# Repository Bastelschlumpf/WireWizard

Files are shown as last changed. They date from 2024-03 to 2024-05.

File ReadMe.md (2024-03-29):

# WireWizard "Under Construction"

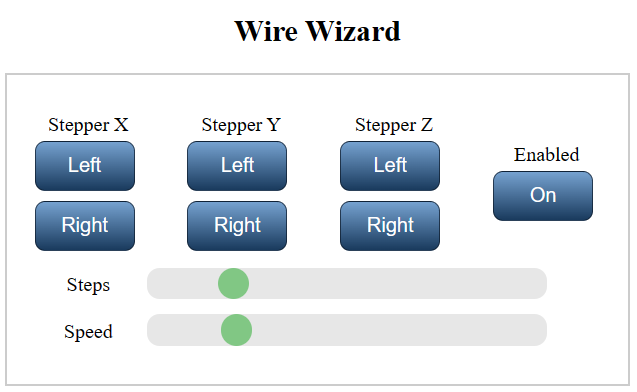
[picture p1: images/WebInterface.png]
WebInterface
 

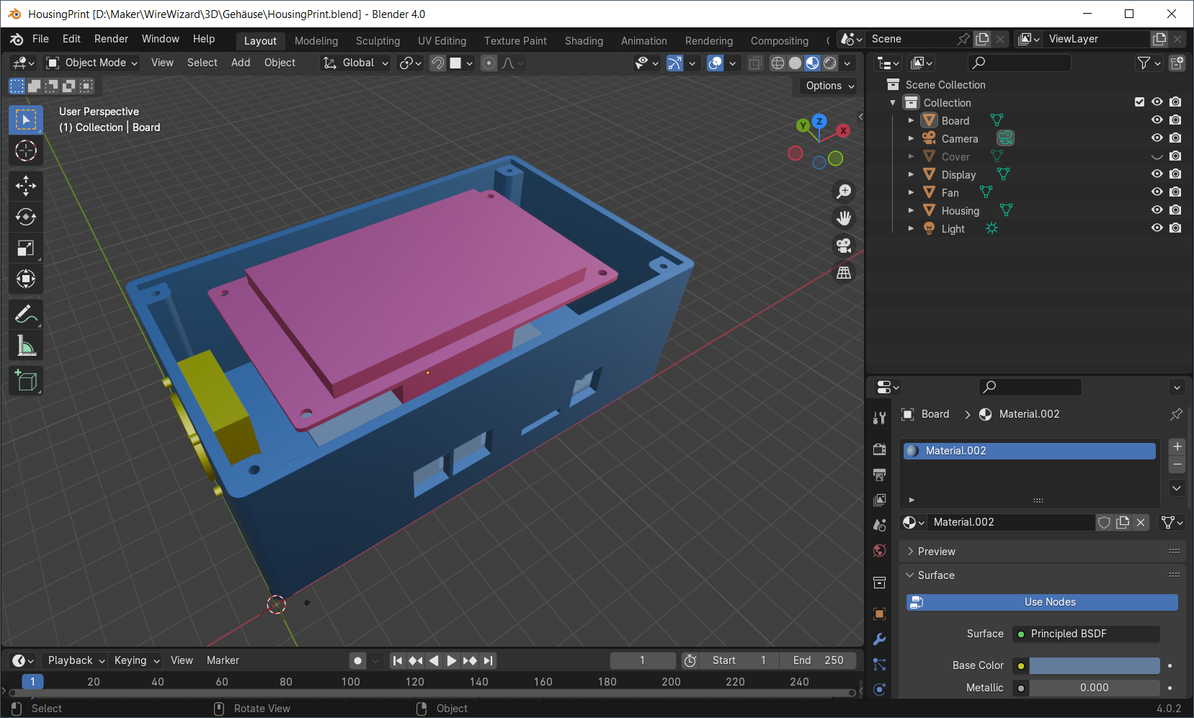
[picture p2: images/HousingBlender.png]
 
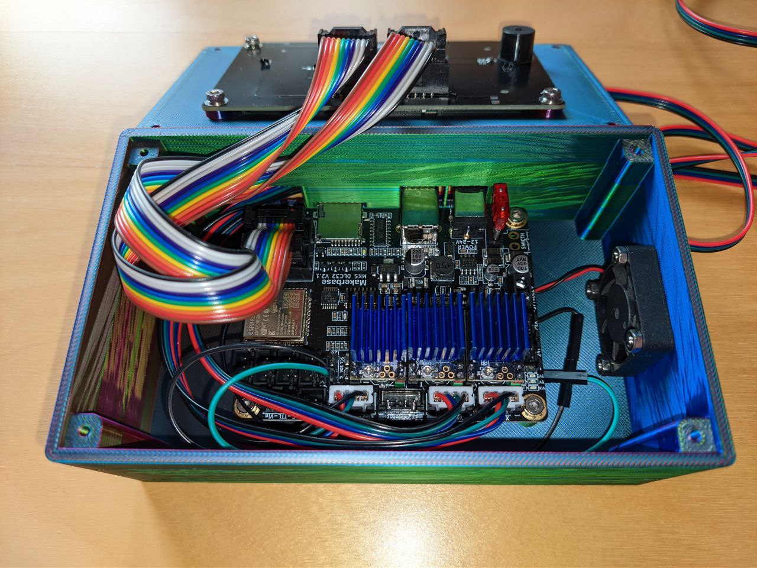
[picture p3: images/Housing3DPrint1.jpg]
 
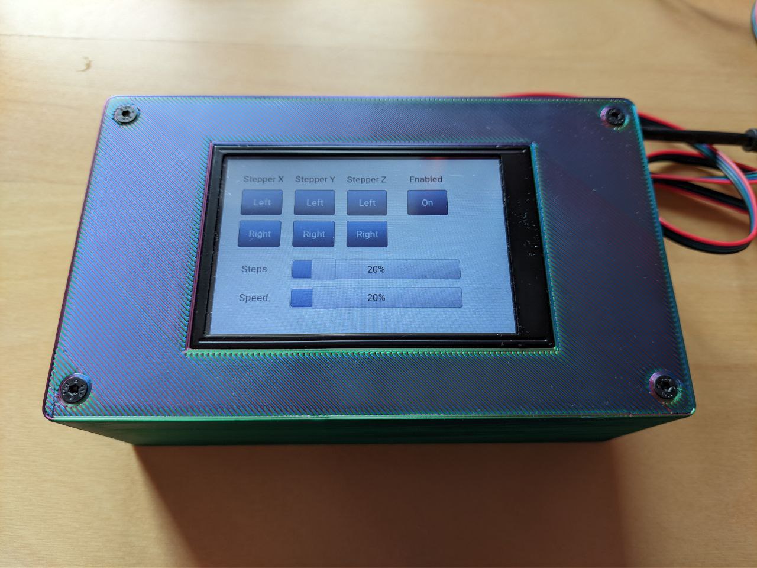
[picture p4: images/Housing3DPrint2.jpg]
 

lvgl Library
  Version 9.0.0
  https://lvgl.io
  
TFT_eSPI Library  
  Version 2.5.43
  https://github.com/Bodmer/TFT_eSPI
  
  **Anpassungen in User_Setup.h**  
  #define ST7796_DRIVER  
  #define TFT_WIDTH  480  
  #define TFT_HEIGHT 320  
  #define TFT_MISO 19  
  #define TFT_MOSI 23  
  #define TFT_SCLK 18  
  #define TFT_CS   25  // Chip select control pin   
  #define TFT_DC   33  // Data Command control pin  
  #define TFT_RST  27  // Reset pin (could connect to RST pin)  
  #define TOUCH_CS 26     // Chip select pin (T_CS) of touch screen  
  // #define SMOOTH_FONT  
  #define SPI_FREQUENCY  40000000  
  #define SPI_TOUCH_FREQUENCY  2000000  

### Special thanks to

**betaone for the universal housing with cover on thingiverse  
https://www.thingiverse.com/thing:1701426**

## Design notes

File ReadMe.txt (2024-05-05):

Gummifüsse
Display schräg
Ein-/Ausschalter

Stepper Klein
  28HS2806A4
Treiber  
  TMC2209
  
Die eingestellte Spannung am TMC22209 Poti muss 0.85 sein für 0.6A
damit es mit dem 28HS2806 Stepper passt. 
https://learn.watterott.com/de/silentstepstick/faq/  

https://github.com/janelia-arduino/TMC2209/blob/main/datasheet/TMC2209_SilentStepStick_datasheet_Rev1.20.pdf

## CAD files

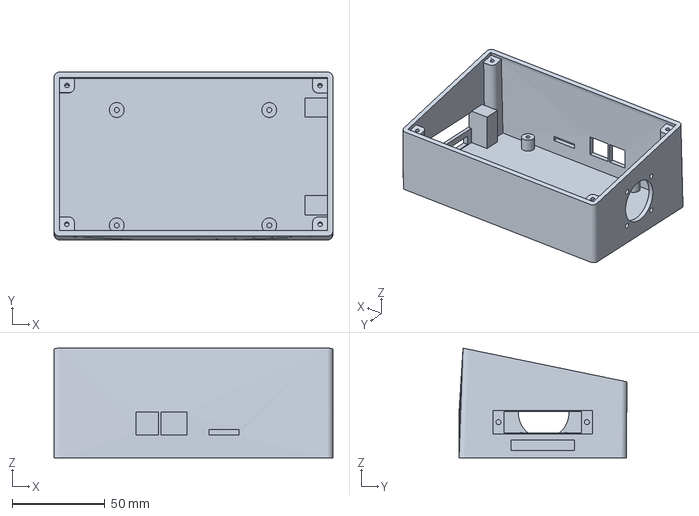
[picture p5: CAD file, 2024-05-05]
housing/ControlBox.3mf
150.0 x 90.3 x 59.0 mm

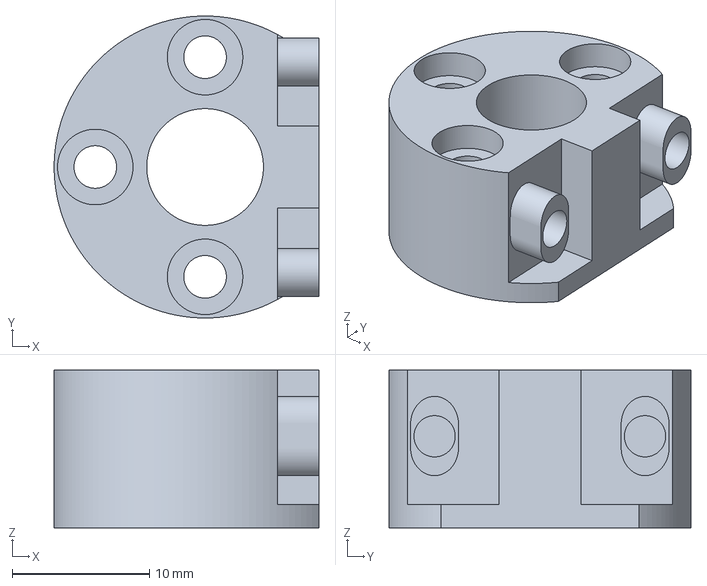
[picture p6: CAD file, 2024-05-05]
housing/parts/KnifeHolder.3mf
19.3 x 22.0 x 11.5 mm

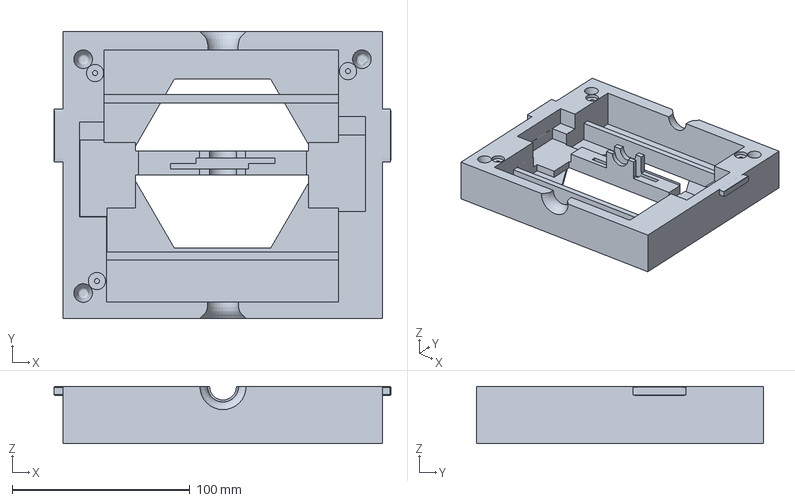
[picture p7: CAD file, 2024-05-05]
housing/CutterBoxCover.3mf
189.9 x 161.7 x 32.1 mm

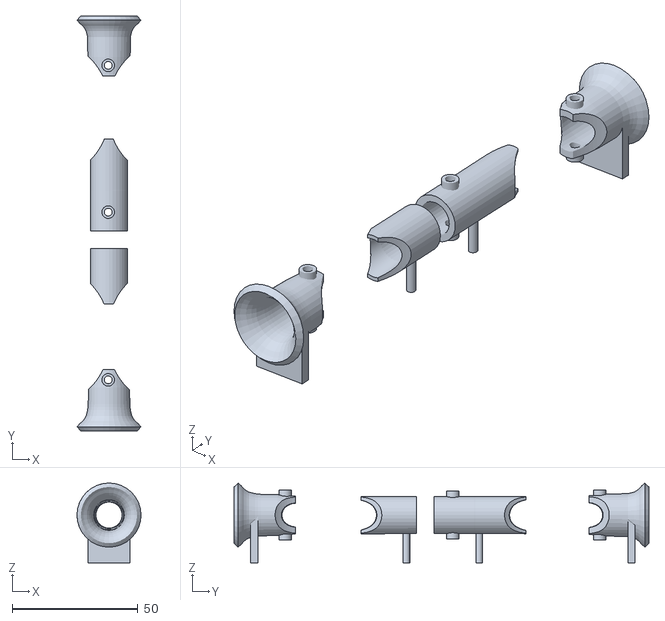
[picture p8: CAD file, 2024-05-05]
housing/parts/Tube.stl
25.5 x 165.0 x 31.8

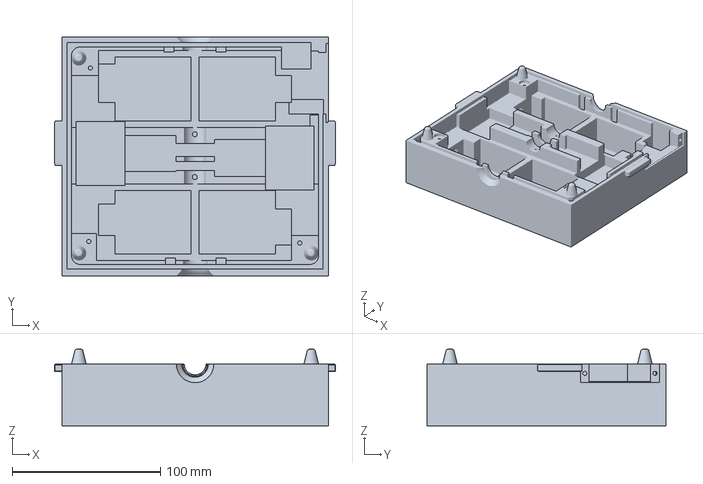
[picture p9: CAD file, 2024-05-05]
housing/CutterBox.3mf
189.9 x 161.7 x 51.8 mm

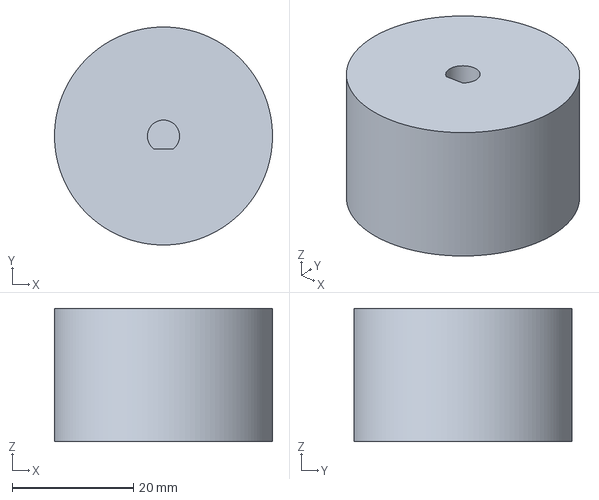
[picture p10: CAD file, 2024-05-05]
housing/parts/DriveRoller.3mf
36.0 x 36.0 x 22.0 mm

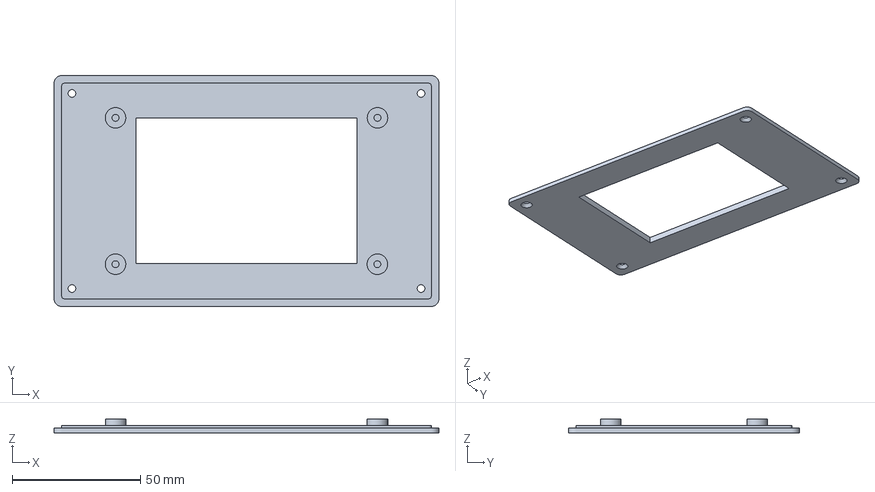
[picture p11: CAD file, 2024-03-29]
housing/ControlBoxCover.3mf
150.0 x 90.0 x 5.52 mm

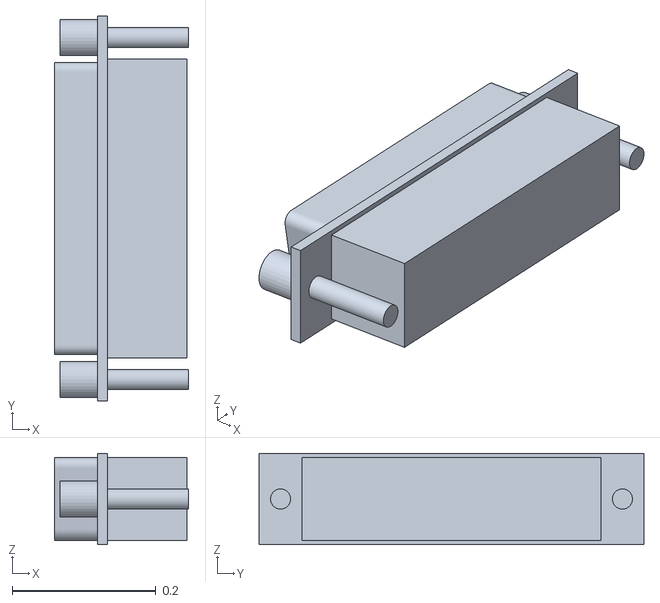
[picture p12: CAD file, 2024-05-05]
housing/parts/D-Sub25.stl
0.187 x 0.535 x 0.127

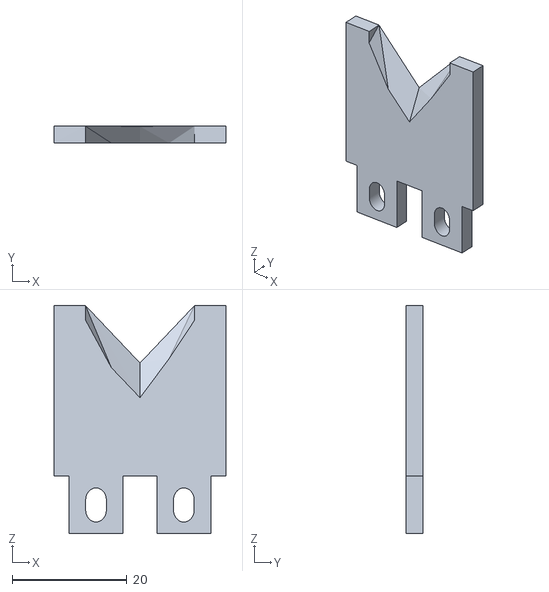
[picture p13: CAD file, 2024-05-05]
housing/parts/Knife.stl
30.0 x 3.00 x 39.8

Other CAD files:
housing/ControlBox.blend
housing/ControlBox.stl
housing/ControlBoxCover.stl
housing/CutterBox.stl
housing/CutterBoxCover.stl
housing/parts/ControlBoard.blend
housing/parts/D-Sub25.blend
housing/parts/Display.blend
housing/parts/DriveRoller.stl
housing/parts/Knife.blend
housing/parts/KnifeHolder.blend
housing/parts/KnifeHolder.stl
housing/parts/LED.blend
housing/parts/Stepper_17HD3401B.blend
housing/parts/Stepper_17HS4023.blend
housing/parts/Tube.blend

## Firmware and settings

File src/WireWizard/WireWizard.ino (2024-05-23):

/*
   Copyright (C) 2024 SFini

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
   You should have received a copy of the GNU General Public License
   along with this program.  If not, see <http://www.gnu.org/licenses/>.
*/
/**
  * @file WireWizard.ino
  * 
  * Main WireWizard file
  */

#include "Config.h"
#define USE_CONFIG_OVERRIDE //!< Switch to use ConfigOverride
#ifdef USE_CONFIG_OVERRIDE
  #include "ConfigOverride.h"
#endif

#include <Arduino.h>
#include <SPI.h>
#include "EventQueue.h"
#include "Sensors.h"
#include "Motors.h"
#include "Controller.h"
#include "Display.h"
#include "WebServer.h"

Motors      motors;
Sensors     sensors;
Controller  controller(motors, sensors);
Display     display;
MyWebServer webServer;


void setup() 
{
  Serial.begin(115200);

  disableCore0WDT();
  disableCore1WDT();

  SPI.begin();

  motors.begin();
  motors.delay(0);
  motors.enable(true);
  motors.enableOnIdle(false);
  sensors.begin();
  controller.begin();
  display.begin();

  // webServer.begin();
}

#define MAX_DELAY 1000
#define MAX_STEPS 10 * 16 * 200

void testCut()
{
  int ticks = millis();

  motors.beep(100);
  motors.delay(1000);

  Serial.println("Fill in");
  ticks = millis();
  motors.stepX(-100000);
  Serial.println("Wait for cutter sensor");
  while (sensors.getY() < 3000) {
    delay(100);
    if (millis() - ticks > 5000) {
      break;
      // return;
    }
  };
  motors.resetSteps();

  Serial.println("Move forward");
  ticks = millis();
  motors.stepX(-100000);
  motors.stepZ(-100000);
  Serial.println("Wait for out sensor");
  while (sensors.getZ() < 3000) {
    delay(100);
    if (millis() - ticks > 5000) {
      break;
      // return;
    }
  };
  motors.resetSteps();

  Serial.println("Move a bit forward");
  ticks = millis();
  motors.stepX(-3000);
  motors.stepZ(-3000);
  while (!motors.isIdle()) {
    delay(100);
    if (millis() - ticks > 5000) {
      break;
      // return;
    }
  }
  motors.resetSteps();

  Serial.println("Cut");
  ticks = millis();
  motors.stepY(4000);
  while (!motors.isIdle()) {
    delay(100);
    if (millis() - ticks > 5000) {
      break;
      // return;
    }
  }
  ticks = millis();
  motors.stepY(-4000);
  while (!motors.isIdle()) {
    delay(100);
    if (millis() - ticks > 5000) {
      break;
      // return;
    }
  }

  Serial.println("Move out");
  ticks = millis();
  motors.stepZ(-200000);
  Serial.println("Wait for out");
  while (sensors.getZ() > 3000) {
    delay(100);
    if (millis() - ticks > 5000) {
      break;
      // return;
    }
  };

  motors.beep(100);
  motors.resetSteps();

  Serial.println("Finish");
}

void loop() 
{
  static int speed = 100;
  static int steps = 16 * 200;

  if (eventQueue.messageWaiting()) {
    Event event;

    if (eventQueue.receive(event)) {
      switch (event.pushButton) {
      case Event::X_LEFT:  motors.stepX(-steps); break;
      case Event::X_RIGHT: motors.stepX( steps); break;
      case Event::Y_LEFT:  motors.stepY(-steps); break;
      case Event::Y_RIGHT: motors.stepY( steps); break;
      case Event::Z_LEFT:  motors.stepZ(-steps); break;
      case Event::Z_RIGHT: motors.stepZ( steps); break;
      case Event::ON:      motors.enable(true);  break;
      case Event::OFF:     motors.enable(false); break;
      case Event::STEPS:  
        steps = event.steps * MAX_STEPS / 100; 
        break;
      case Event::SPEED:  
        motors.delay(MAX_DELAY * (100.0 - event.speed) / 100.0); 
        break;
      case Event::START:  
        controller.move(100);
        controller.cut();
        controller.eject(100);
        break;
      }
    }
  }

  int valueX = sensors.getX();
  int valueY = sensors.getY();
  int valueZ = sensors.getZ();

  display.setValueX("X: " + String(valueX));
  display.setValueY("Y: " + String(valueY));
  display.setValueZ("Z: " + String(valueZ));

  // Serial.println("Lichtschranke (X, Y, Z): " + String(valueX) + ", " + String(valueY) + ", " + String(valueZ));

/*
  if (valueX > 3000) {
    Serial.println("In sensor");
    testCut();
  }
  */

  delay(100);
}

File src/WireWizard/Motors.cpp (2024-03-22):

/*
   Copyright (C) 2024 SFini

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
   You should have received a copy of the GNU General Public License
   along with this program.  If not, see <http://www.gnu.org/licenses/>.
*/
/**
  * @file Motors.cpp
  * 
  * Stepper Interface
  */

#include <SPI.h>
#include <I2S.h>
#include <freertos/FreeRTOS.h>
#include <freertos/task.h>
#include "Motors.h"

#define ENABLE_BIT  0
#define X_STEP_BIT  1
#define X_DIR_BIT   2
#define Y_STEP_BIT  3
#define Y_DIR_BIT   4
#define Z_STEP_BIT  5
#define Z_DIR_BIT   6
#define BEEP_BIT    7

const int latchPin = GPIO_NUM_17;
const int clockPin = GPIO_NUM_16;
const int dataPin  = GPIO_NUM_21;

Motors::Motors()
{
  reset();
}

void Motors::enable(bool en)       
{ 
  enabled = en; 
  if (!enabled){
    resetSteps(); 
  }
}

void Motors::reset()
{
  enabled       = false;
  enabledOnIdle = false;
  currPosX      = 0;
  currPosY      = 0;
  currPosZ      = 0;
  doStepsX      = 0;
  doStepsY      = 0;
  doStepsZ      = 0;
  delayUs       = 0;
  beepMs        = 0;
}

void Motors::resetSteps()
{
  doStepsX = 0;
  doStepsY = 0;
  doStepsZ = 0;
  beepMs   = 0;
}

void Motors::serialOut(byte value)
{
  digitalWrite(latchPin, LOW);                  // Schieberegister-Puffer sperren
  shiftOut(dataPin, clockPin, MSBFIRST, value); // Wert über SPI senden
  digitalWrite(latchPin, HIGH);                 // Schieberegister-Puffer freigeben
}

void Motors::setEnableBit(byte &value, short enableBit, bool enable)
{
  if (enable) {
    bitClear(value, enableBit);
  } else {
    bitSet(value, enableBit);
  }
}

void Motors::setBeepBit(byte &value, short beepBit, TickType_t startTickCount, long &beepMs)
{
  uint32_t elapsedTimeMs = (xTaskGetTickCount() - startTickCount) * portTICK_PERIOD_MS;

  if (elapsedTimeMs > beepMs) {
    beepMs = 0;
  }
  if (beepMs > 0) {
    bitSet(value, beepBit);
  } else {
    bitClear(value, beepBit);
  }
}

void Motors::setStepperBit(byte &value, short dirBit, short stepBit, long &doSteps, long &pos)
{
  bitClear(value, stepBit);
  if (doSteps != 0) {
    bitSet(value, stepBit);
    if (doSteps > 0) {
      bitSet(value, dirBit);
      doSteps--;
      pos++;
    } else {
      bitClear(value, dirBit);
      doSteps++;
      pos--;
    }
  }
}

void Motors::motorTask(void *parg) 
{
  Motors *motors = (Motors *) parg;

  if (motors) {
    TickType_t startTickCount = xTaskGetTickCount();

    motors->serialOut(0b00000001);
    while (true) {
      if ((!motors->enabled && motors->isIdleBeep()) || (motors->isIdleX() && motors->isIdleY() &&motors->isIdleZ())) {
        if (motors->enabledOnIdle) {
          motors->serialOut(0b00000000);
        } else {
          motors->serialOut(0b00000001);
        }
        vTaskDelay(pdMS_TO_TICKS(1));
        startTickCount = xTaskGetTickCount();
      } else {
        byte value = 0b00000000;

        motors->setEnableBit(value, ENABLE_BIT, motors->enabled);
        if (motors->enabled) {
          motors->setStepperBit(value, X_DIR_BIT, X_STEP_BIT, motors->doStepsX, motors->currPosX);
          motors->setStepperBit(value, Y_DIR_BIT, Y_STEP_BIT, motors->doStepsY, motors->currPosY);
          motors->setStepperBit(value, Z_DIR_BIT, Z_STEP_BIT, motors->doStepsZ, motors->currPosZ);
        }
        motors->setBeepBit(value, BEEP_BIT, startTickCount, motors->beepMs);

        motors->serialOut(value);
        ets_delay_us(10);

        bitClear(value, X_STEP_BIT);
        bitClear(value, Y_STEP_BIT);
        bitClear(value, Z_STEP_BIT);

        motors->serialOut(value);
        ets_delay_us(100);

        if (motors->delayUs > 0) {
          ets_delay_us(motors->delayUs);
        }
      }
    }
  }
}

void Motors::begin()
{
  pinMode(latchPin, OUTPUT);
  pinMode(clockPin, OUTPUT);
  pinMode(dataPin, OUTPUT);

  xTaskCreatePinnedToCore(motorTask, "motorTask", 10000, this, 1, nullptr, 0);
}

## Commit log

2024-03-29 Test housing
    [BoardParts.blend, DisplayParts.blend, Housing.3mf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]
2024-03-29 Thanks to betaone for the housing
2024-05-05 New version
    [BoardParts.blend, ControlBoard.blend, ControlBox.3mf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]
2024-05-05 More space for display
    [ControlBox.3mf, ControlBox.blend, ControlBox.stl]
2024-05-23 New Test Cut

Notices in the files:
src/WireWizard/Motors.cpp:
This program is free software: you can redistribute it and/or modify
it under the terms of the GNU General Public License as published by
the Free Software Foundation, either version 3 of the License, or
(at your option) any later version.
